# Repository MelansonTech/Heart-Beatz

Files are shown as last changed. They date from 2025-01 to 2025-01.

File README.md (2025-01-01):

Project Title: Heart Beats - Bass Note Detector
Overview:
Conceived and developed "Heart Beats," a solo endeavor aimed at creating a cost-effective, portable bass note detector with digital filters for precise bass detection and PID-controlled AGC to maintain consistent performance across a wide dynamic range. The system features an LED indicator for real-time feedback upon detecting a bass note, all powered by a single AAA battery. The pendant-style enclosure, crafted using Fusion 360, adds both functionality and aesthetics to the product.
Project Objectives:
1.	Objective 1: Design a low-cost bass note detector capable of handling a wide dynamic range.
2.	Objective 2: Implement digital filters for accurate bass note detection in music.
3.	Objective 3: Utilize PID controlled AGC to maintain consistent performance across varying input levels.
4.	Objective 4: Design a portable product with a compact form factor.
5.	Objective 5: Create an aesthetically pleasing pendant-style enclosure using Fusion 360.
Role and Responsibilities:
As the sole developer:
•	Conducted market research to identify the need for a portable and affordable bass note detector.
•	Developed digital filter algorithms for accurate bass note detection.
•	Engineered the hardware components, incorporating PID controlled AGC for dynamic range adjustment.
•	Designed and prototyped the low-power circuit ensuring compatibility with a single AAA battery.
•	Utilized Fusion 360 to design a pendant-style enclosure for user-friendly and stylish portability.
Design Process:
1.	Conceptualization: Identified the need for a portable bass note detector and outlined the key features required.
2.	Algorithm Development: Developed digital filters for precise bass note detection over a wide dynamic range.
3.	Hardware Implementation: Designed the hardware components, incorporating PID controlled AGC for dynamic range adjustment.
4.	Power Efficiency: Engineered a low-power circuit to ensure portability with a single AAA battery.
5.	Enclosure Design: Utilized Fusion 360 to design a pendant-style enclosure, considering both aesthetics and practicality.
Key Features:
1.	Digital Filters: Implemented digital filters for precise bass note detection over a wide dynamic range.
2.	PID Controlled AGC: Utilized PID control for Automatic Gain Control, ensuring consistent performance.
3.	Portability: Powered by a single AAA battery for on-the-go use without compromising performance.
4.	Compact Form Factor: Designed for easy portability and convenient use.
5.	LED Indicator: Illuminates an LED upon detecting a bass note, providing real-time feedback to the user.
6.	Pendant-style Enclosure: Designed a stylish and user-friendly pendant enclosure using Fusion 360.
Tools and Technologies:
1.	Algorithm Development: MATLAB for digital filter development.
2.	Hardware Design: Altium Designer for schematic and layout.
3.	Enclosure Design: Fusion 360 for 3D modeling and design.
Results and Achievements:
The "Heart Beats" project stands as a testament to individual innovation, successfully delivering a cost-effective, portable, and stylish bass note detector with precise digital filtering and PID-controlled AGC. The incorporation of a single AAA battery ensures portability, making it an ideal companion for music enthusiasts on the go.
Lessons Learned:
The project provided valuable insights into optimizing power consumption while maintaining performance. The Fusion 360 enclosure design emphasized the importance of both functionality and aesthetics in user-oriented products.
Conclusion:
The "Heart Beats" project exemplifies the capabilities of an individual developer in integrating digital signal processing, control systems, and industrial design to create a unique and portable bass note detector. The combination of accurate bass detection, PID-controlled AGC, and a stylish pendant-style enclosure makes "Heart Beats" a standout product in the market.
Additional Resources:
•	Link to Schematic Diagram
•	Link to Fusion 360 Enclosure Model

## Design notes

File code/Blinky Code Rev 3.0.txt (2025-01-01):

/*
 * ======== Standard MSP430 includes ========
 */
#include <msp430.h>

/*
 * ======== Grace related includes ========
 */
#include <ti/mcu/msp430/Grace.h>

int findaverage(int outavg[150], unsigned int H);
/*
 *  ======== main ========
 */
int main(void)
{
    Grace_init();   // Activate Grace-generated configuration

    	unsigned int k;   //declare unsigned integers
    	unsigned int B =0;//

    	int filtered=0; // Declare integers
  		int peak10 = 0;
  		int Adata=0;
  		int CenterTap=0;

  		int outarr[150]; // Declare Arrays

  		int RegX1[4],RegX2[4],RegY1[4],RegY2[4];

  		const float a1[]={-1.169925255,-1.402167657,-1.120723799,-1.649948614};
  		const float a2[]={0.6360640657,0.6962444294,0.8186383078,0.8846651141}; //Set the Digital filter coefficients
  		const float b0[]={-0.173675154,-0.1901072,-0.1910775392,-0.2064887892};
  		const float b2[]={0.173675154,0.1901072,0.1910775392,0.2064887892};

  		for (k=0; k>3; ++k)

  			{
  			RegX1[k]=0;
  			RegX2[k]=0;				//Clear the Digital filter multiply\accumulate registers
  			RegY1[k]=0;
  			RegY2[k]=0;
  			}

  				//-------------------------------------------------------------------------------------------------------------------------------------------------------------------------------------------------------------------------------------

  	while(1) // endless loop

  	{

  		if (P2OUT && BIT4 == BIT4) // check to see if P2OUT is equal to 00001000 and excute code if true.
  								   // Wait for timer to finish, then begin processing next data point.
  								   // A Timer is Set at 1000hz intervals and is used to set the sample rate of the ADC. P2OUT bit 4 is set by the timer.

  		{

  			ADC10CTL0 |= ENC + ADC10SC; //Start ADC

  						 /* Loop until ADC10IFG is set indicating ADC conversion complete */
  						 while ((ADC10CTL0 & ADC10IFG) == 0);
  						 Adata = ADC10MEM;

  						 for(k=0; k<3; k++) /* 3 + 0 is the number of sections - stop when 4 is reached*/

  						 {

  						 CenterTap = ((Adata * b0[k]) + (b2[k] * RegX2[k]));
  						 filtered = (CenterTap - (a1[k] * RegY1[k]) - (a2[k] * RegY2[k]));

  						 	   RegX2[k] = RegX1[k];
  						 	   RegX1[k] = Adata;
  						 	   RegY2[k] = RegY1[k];
  						 	   RegY1[k] = filtered;
  						 	   	  Adata = filtered;
  						 }

  			outarr[B]=filtered; //get 150 samples of filter
  			++B; //Set next point in array
  			P2OUT &= ~BIT4; //turn off bit 4 - timer will reset to high state and then the next sample can be processed.

  		}

			if (B > 149) //Check to see if a 150 samples have been gathered

			{

				TA0CTL &= ~BIT4; //Stop sampling and processing audio data through digital filter.
			  	peak10 = findaverage(outarr,149)*2; //find the average of the peaks of the data and multiple by 2
				B=0; // Set B to zero to begin gathering a new set of data points

			}

			if (filtered > peak10) //Check to see if the if there is a filtered data point is higher then the average of the peaks of the last 150 samples of filtered data

				 {

 					P1OUT |= BIT0;  // Turn on LED
					TA1CTL |= BIT4; //Start Timer

				}
s
  	}

}

	int findaverage(int outavg[], unsigned int H)

		{

		unsigned int X=0; //declare unsigned integers
		unsigned int D = 0;
		unsigned int M = 0;

		int peak= 0;
		int peakavg = 0;//declare integers

			for (X= 0; X < H; ) //run loop for number of samples points-->149

		  	{

				peak = 0; //set peak to zero

//-------------------------------------------------------------------------------------------------------------------------------
	//Find highest point out of every 6 data points for the total number of samples and average them.

				for (M=0;M<6;++M)

		  	    	 {

						if (outavg[X] > 0)
						{
		  	    		  if (outavg[X]> peak)
		  	    		  {
		  	    		    peak = outavg[X];
		  	    		  }
		  	    		}

						++X;
		  	    	 }

			 	 	 peakavg += peak;

			 	 	 ++D;

		  	 }

	peakavg /= D;

//-----------------------------------------------------------------------------------------------------------------------

		  	  if (peakavg < 15) //Min Peak average is 15

		  	  {
		  	  	peakavg = 15;
		  	  }

		  	TA0CTL |= BIT4; // Turn timer A0 back on and begin ADC and digial filter processing.
		  	return (peakavg);
}

/*
 *  This file is automatically generated and does not require a license
 *
 *  ==== WARNING: CHANGES TO THIS GENERATED FILE WILL BE OVERWRITTEN ====
 *
 *  To make changes to the generated code, use the space between existing
 *      "USER CODE START (section: <name>)"
 *  and
 *      "USER CODE END (section: <name>)"
 *  comments, where <name> is a single word identifying the section.
 *  Only these sections will be preserved.
 *
 *  Do not move these sections within this file or change the START and
 *  END comments in any way.
 *  ==== ALL OTHER CHANGES WILL BE OVERWRITTEN WHEN IT IS REGENERATED ====
 *
 *  This file was generated from
 *      C:/ti/grace_3_10_00_82/packages/ti/mcu/msp430/csl/interrupt_vectors/InterruptVectors_init.xdt
 */
#include <msp430.h>
#include "_Grace.h"

/* USER CODE START (section: InterruptVectors_init_c_prologue) */

/* USER CODE END (section: InterruptVectors_init_c_prologue) */

/*
 *  ======== InterruptVectors_graceInit ========
 */
void InterruptVectors_graceInit(void)
{
}

/* Interrupt Function Prototypes */

/*
 *  ======== Timer0_A3 Interrupt Service Routine ======== 
 */
#pragma vector=TIMER0_A0_VECTOR
__interrupt void TIMER0_A0_ISR_HOOK(void)
{
    /* USER CODE START (section: TIMER0_A0_ISR_HOOK) */
  P2OUT |=BIT4;

    /* USER CODE END (section: TIMER0_A0_ISR_HOOK) */
}

/*
 *  ======== Timer0_A3 Interrupt Service Routine ======== 
 */
#pragma vector=TIMER0_A1_VECTOR
__interrupt void TIMER0_A1_ISR_HOOK(void)
{
    /* USER CODE START (section: TIMER0_A1_ISR_HOOK) */
    /* replace this comment with your code */
    /* USER CODE END (section: TIMER0_A1_ISR_HOOK) */
}

/*
 *  ======== Timer1_A3 Interrupt Service Routine ======== 
 */
#pragma vector=TIMER1_A0_VECTOR
__interrupt void TIMER1_A0_ISR_HOOK(void)
{
    /* USER CODE START (section: TIMER1_A0_ISR_HOOK) */

	P1OUT &= ~BIT0; // turn off the LED
	TA1CTL &=~BIT4;// turn off timer A1

	/* USER CODE END (section: TIMER1_A0_ISR_HOOK) */
}

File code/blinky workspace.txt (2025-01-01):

/*
 * ======== Standard MSP430 includes ========
 */
#include <msp430.h>

/*
 * ======== Grace related includes ========
 */
#include <ti/mcu/msp430/Grace.h>

int findaverage(int outavg[150], unsigned int H);
/*
 *  ======== main ========
 */
int main(void)
{
    Grace_init();   // Activate Grace-generated configuration

    	unsigned int k;   //declare unsigned integers
   // 	unsigned int B =0;//
    	//int PS_offCnt=0;
    //	unsigned int underPeakTest = 0;
	//	unsigned int underPeakCounter = 0;
	//	unsigned int underPeakDetect = 0;
	//	unsigned int underPeakTestdiv = 0;
		//unsigned int peakDetectDelay = 0;
    //	unsigned int adcsample = 149;
    	int filtered=0; // Declare integers
  		unsigned int peak10 = 0;
  	//	unsigned int samplesum;
  		int Adata=0;
  		int CenterTap=0;
  		int Adata1=0;
  		int CenterTap1=0;
  		int filtered1=0;

  	//	int outarr[150]; // Declare Arrays

  		int RegX1[4],RegX2[4],RegY1[4],RegY2[4];

  		const float a1[]={-1.169925255,-1.402167657,-1.120723799,-1.649948614};
  		const float a2[]={0.6360640657,0.6962444294,0.8186383078,0.8846651141}; //Set the Digital filter coefficients
  		const float b0[]={-0.173675154,-0.1901072,-0.1910775392,-0.2064887892};
  		const float b2[]={0.173675154,0.1901072,0.1910775392,0.2064887892};

  		int RegX11 =0;
  		int RegY11 = 0;

  		const float a11 =  -0.678222413648525757;
  		//const float a21 = 0; //Set the Digital filter coefficients
  		const float b01 = 0.160888793175737121;
  		const float b11 = 0.160888793175737121;

  		for (k=0; k>3; ++k)

  			{
  			RegX1[k]=0;
  			RegX2[k]=0;				//Clear the Digital filter multiply\accumulate registers
  			RegY1[k]=0;
  			RegY2[k]=0;
  			}

  	//P1OUT &= 0;
  	//P1OUT |=BIT0; // turn on the LED/also used to as a flag to debounce the on off switch
  //	TA1CTL &=~BIT4;

  				//-------------------------------------------------------------------------------------------------------------------------------------------------------------------------------------------------------------------------------------

  	//while(P1OUT && BIT0 == BIT0)

 // 	{

  //	TA1CTL |= BIT4; //Start Timer//wait for the on\off button to be released

  //	if (!(P2IN & BIT1))

  //	{

  	//	TA1CCR0 += 600;

  //	}

  //	}

 // 	P2OUT |= BIT2;//latch the power supply on
  //	TA1CCR0 = 600;

  	while(1) // endless loop

  	{

  		P1OUT &= ~BIT1;

  		if (P2OUT && BIT4 == BIT4) // check to see if P2OUT is equal to 00001000 and excute code if true.
  								   // Wait for timer to finish, then begin processing next data point.
  								   // A Timer is Set at 1000hz intervals and is used to set the sample rate of the ADC. P2OUT bit 4 is set by the timer.

  		{

  			P2OUT &= ~BIT4; //turn off bit 4 - timer will reset to high state and then the next sample can be processed.
  			P1OUT |= BIT1;
  			ADC10CTL0 |= ENC + ADC10SC; //Start ADC

  						 /* Loop until ADC10IFG is set indicating ADC conversion complete */
  						 while ((ADC10CTL0 & ADC10IFG) == 0);
  						 Adata = ADC10MEM;

  						 for(k=0; k<3; k++) /* 3 + 0 is the number of sections - stop when 4 is reached*/

  						 {

  						 CenterTap = ((Adata * b0[k]) + (b2[k] * RegX2[k]));
  						 filtered = (CenterTap - (a1[k] * RegY1[k]) - (a2[k] * RegY2[k]));

  						 	   RegX2[k] = RegX1[k];
  						 	   RegX1[k] = Adata;
  						 	   RegY2[k] = RegY1[k];
  						 	   RegY1[k] = filtered;
  						 	   Adata = filtered;
  						 }

  		if (filtered < 0)

  			{

  			filtered *= -1;

  			}

  		 CenterTap1 = ((filtered * b01) + (b11 * RegX11));
  		 filtered1 = (CenterTap1 - (a11 * RegY11));

  		  		 //RegX2[k] = RegX1[k];
  		  		 RegX11 = filtered;
  		  		// RegY2[k] = RegY1[k];
  		  		 RegY11 = filtered1;
  		  		 peak10 = filtered1;

  			if (peak10 < 5)

  			{
				 peak10 = 5;

  			}

  			peak10 *= 3;

		//	if (B > adcsample) //Check to see if a 150 samples have been gathered

		//	{

				//TA0CTL &= ~BIT4; //Stop sampling and processing audio data through digital filter.
			  	//peak10 = findaverage(outarr, B); //find the average of the peaks of the data and multiple by 2
			//	B=0; // Set B to zero to begin gathering a new set of data points

		//	}
				/*
				if (!(P2IN & BIT1))

				{

		 	PS_offCnt += 1;

		}

				else

				{

				PS_offCnt = 0;

				}

				if (PS_offCnt > 3 )

				{

					while(1)

				{
					P2OUT &= ~BIT2;

				}

				}

			}

 */
			//filtered *= adcsample;

			if (filtered > peak10) //Check to see if the if there is a filtered data point is higher then the average of the peaks of the last 150 samples of filtered data

				 {

				P1OUT |= (BIT0 + BIT2);  // Turn on LED
				TA1CTL |= BIT4; //Start Timer

				//P2OUT &= ~BIT4; //turn off bit 4 - timer will reset to high state and then the next sample can be processed.

  /*
				if (underPeakTest < filtered)

				{
				underPeakTest = filtered;
				underPeakTestdiv = underPeakTest/2;
				underPeakCounter = 10;
				underPeakDetect = 1;

				}

				 }

			if (underPeakDetect == 1)

			{
			//	peakDetectDelay++;

		//	if (peakDetectDelay == 8)

		//		{

				if ( filtered < underPeakTestdiv)

				{

				underPeakCounter++;

				}

				else

				{

		//			peakDetectDelay = 0;
					underPeakCounter--;

				}

			if (underPeakCounter > 100)

				{

				P1OUT |= (BIT0 + BIT2);  // Turn on LED
				TA1CTL |= BIT4; //Start Timer
				underPeakDetect = 0;
				//peakDetectDelay = 0;
				underPeakTest = 0;

				}

			if (underPeakCounter < 8)

			{

			underPeakDetect = 0;
			underPeakTest = 0;

			}

   */

  	}

}

}

}
/*

	int findaverage(int outavg[], unsigned int H)

		{

		unsigned int X=0; //declare unsigned integers
		unsigned int D = 0;
		unsigned int M = 0;

		int peak= 0;
		int peakavg = 0;//declare integers

			for (X= 0; X < H; ) //run loop for number of samples points-->149

		  	{

				peak = 0; //set peak to zero

//-------------------------------------------------------------------------------------------------------------------------------
	//Find highest point out of every 6 data points for the total number of samples and average them.

				for (M=0;M<6;++M)

		  	    	 {

						if (outavg[X] > 0)
						{
		  	    		  if (outavg[X]> peak)
		  	    		  {
		  	    		    peak = outavg[X];
		  	    		  }
		  	    		}

						++X;
		  	    	 }

			 	 	 peakavg += peak;

			 	 	 ++D;

		  	 }

	peakavg /= D;

//-----------------------------------------------------------------------------------------------------------------------

		  	  if (peakavg < 5) //Min Peak average is 15

		  	  {
		  	  	peakavg = 5;
		  	  }

		  	  peakavg *= 2.5;

		  	TA0CTL |= BIT4; // Turn timer A0 back on and begin ADC and digial filter processing.
		  	return (peakavg);

}
*/

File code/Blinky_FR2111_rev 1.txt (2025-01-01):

#include <msp430.h>

//void Software_Trim();                       // Software Trim to get the best DCOFTRIM value
//#define MCLK_FREQ_MHZ 8                     // MCLK = 8MHz

unsigned int ADCCOMPLETE_FLAG = 0;
int Adata;
int main(void)
{

    WDTCTL = WDTPW | WDTHOLD;                 // Stop WDT

        // Configure one FRAM waitstate as required by the device datasheet for MCLK
        // operation beyond 8MHz _before_ configuring the clock system.
        FRCTL0 = FRCTLPW | NWAITS_1;

        __bis_SR_register(SCG0);                     // disable FLL
        CSCTL3 |= SELREF__XT1CLK;                    // Set XT1 as FLL reference source
        CSCTL0 = 0;                                  // clear DCO and MOD registers
        CSCTL1 &= ~(DCORSEL_7);                      // Clear DCO frequency select bits first
        CSCTL1 |= DCORSEL_5;                         // Set DCO = 16MHz
        CSCTL2 = FLLD_0 + 487;                       // DCOCLKDIV = 16MHz
        __delay_cycles(3);
        __bic_SR_register(SCG0);                     // enable FLL
        while(CSCTL7 & (FLLUNLOCK0 | FLLUNLOCK1));   // FLL locked

  /*
        __bis_SR_register(SCG0);                // disable FLL
       CSCTL3 |= SELREF__REFOCLK;              // Set REFO as FLL reference source
       CSCTL1 = DCOFTRIMEN_1 | DCOFTRIM0 | DCOFTRIM1 | DCORSEL_3;// DCOFTRIM=3, DCO Range = 8MHz
       CSCTL2 = FLLD_0 + 243;                  // DCODIV = 8MHz
       __delay_cycles(3);
       __bic_SR_register(SCG0);                // enable FLL
       Software_Trim();                        // Software Trim to get the best DCOFTRIM value

       CSCTL4 = SELMS__DCOCLKDIV | SELA__REFOCLK; // set default REFO(~32768Hz) as ACLK source, ACLK = 32768Hz
                                               // default DCODIV as MCLK and SMCLK source
*/

    // GPIO config

       P1DIR |= BIT1;
       P2DIR |= BIT0 + BIT1;                    // P2.0 and P2.1 output
       P2SEL0 |= BIT0 + BIT1;                   // P2.0 and P2.1 options select
       P1SEL0 |= BIT5;                          // Configure ADC A1 pin
       P1SEL1 |= BIT5;

       // timer config
      const unsigned int TimerPeriod = 26666;
      const unsigned int AGC_duty = 14500;
      const unsigned int AmpRef_duty = 6060;

          // Disable the GPIO power-on default high-impedance mode to activate
          // previously configured port settings
          PM5CTL0 &= ~LOCKLPM5;
          SYSCFG3 |= TBRMP;                         //0b = P1.x is selected P1.6 and P1.7  1b = P2.0 and P2.1
          TB0CCR0 = TimerPeriod-1;                  // PWM Period
          TB0CCTL1 = OUTMOD_7;                      // CCR1 reset/set
          TB0CCR1 = AmpRef_duty;                       // CCR1 PWM duty cycle
          TB0CCTL2 = OUTMOD_7;                      // CCR2 reset/set
          TB0CCR2 = AGC_duty;                       // CCR2 PWM duty cycle
          TB0CTL = TBSSEL__SMCLK | MC__UP | TBCLR;  // SMCLK, up mode, clear TBR
          TB0CCTL0 |= CCIE;

          // Disable the GPIO power-on default high-impedance mode to activate
             // previously configured port settings
             PM5CTL0 &= ~LOCKLPM5;

             // Configure ADC10
             ADCCTL0 |= ADCSHT_2 | ADCON;                              // ADCON, S&H=16 ADC clks
             ADCCTL1 |= ADCSHP;                                        // ADCCLK = MODOSC; sampling timer
             ADCCTL2 |= ADCRES;                                        // 10-bit conversion results
             ADCIE |= ADCIE0;                                          // Enable ADC conv complete interrupt
             ADCMCTL0 |= ADCINCH_5 | ADCSREF_1;                        // A1 ADC input select; Vref=1.5V

             // Configure reference
             PMMCTL0_H = PMMPW_H;                                      // Unlock the PMM registers
             PMMCTL2 |= INTREFEN;                                      // Enable internal reference
             __delay_cycles(400);                                      // Delay for reference settling

        unsigned int k=0;                           //declare unsigned integers
        unsigned int LEDTIMER=0;
        int peakAvg = 0;
        int BassBoundryNow = 0;
        int Peak_search_Arr_i =0;
        int Peak_search_Arr[64];
        int sampleCount=0;                            // Declare integers
        int SampleCountLimit = 255;
        int Peak_search_window = 0;
        int BassBoundry = 0;
        int filtered = 0;
        int CenterTap=0;
        int flipFlop = 0;

       // int Peak_search_Arr[25]; // Declare Arrays

        //PID Variables

         int INT_LIMIT = 5;
         int setpoint = 700;                        //PID controller input
         int peakHold_Now;
         int peakHold_Last;
         float error;
         float errSum;
         float dErr;
         float PID_out;
         float kp = 0.02;
         float ki = 0.0001;
         float kd = 0.01;
         int peakHold_decay = 1;
         P1OUT |= BIT1;

     ////    for (k=0; k < 25; ++k)

        //     {
         //    Peak_search_Arr[k]=0;   //clear the avg filter array
       //      }

                  int RegX1[4],RegX2[4],RegY1[4],RegY2[4];

                  const float a1[]={-1.169925255,-1.402167657,-1.120723799,-1.649948614};
                  const float a2[]={0.6360640657,0.6962444294,0.8186383078,0.8846651141}; //Set the Digital filter coefficients
                  const float b0[]={-0.173675154,-0.1901072,-0.1910775392,-0.2064887892};
                  const float b2[]={0.173675154,0.1901072,0.1910775392,0.2064887892};

                  for (k=0; k<3; ++k)

                      {
                      RegX1[k]=0;
                      RegX2[k]=0;             //Clear the Digital filter multiply\accumulate registers
                      RegY1[k]=0;
                      RegY2[k]=0;
                      }

                          //-------------------------------------------------------------------------------------------------------------------------------------------------------------------------------------------------------------------------------------

              //__delay_cycles(1600000);

              while(1) // endless loop

              {
                  __bis_SR_register(LPM0_bits | GIE);

                  if (ADCCOMPLETE_FLAG == 1) // check to see if P2OUT is equal to 00001000 and excute code if true.
                                             // Wait for timer to finish, then begin processing next data point.
                                             // A Timer is Set at 1000hz intervals and is used to set the sample rate of the ADC. P2OUT bit 4 is set by the timer.

                  {

                     // P1OUT ^=BIT1;
                      ADCCOMPLETE_FLAG = 0;
                      ADCCTL0 |= ADCENC | ADCSC;             // Sampling and conversion start
                      __bis_SR_register(LPM0_bits | GIE);

                     if  (Adata > peakHold_Now) {                  // get and hold the peak to be used for PID controller

                      peakHold_Now += Adata/10;

                     }

                      peakHold_Now -=peakHold_decay;                         //slowly discharge the peak

                      error =  setpoint - peakHold_Now;
                      errSum += error;

                      if (errSum > 100)
                      {
                          errSum = INT_LIMIT;
                      }

                      if (errSum < -INT_LIMIT){

                          errSum = -INT_LIMIT;
                      }

                      dErr = peakHold_Now - peakHold_Last;

                      PID_out = (kp * error) + (ki *errSum) + (kd* dErr);

                      peakHold_Last = peakHold_Now;

                      TB0CCR2 += PID_out;

                      if (TB0CCR2 > 14000){

                          TB0CCR2 = 14000;
                      }

                      if (TB0CCR2 < 10500){

                          TB0CCR2 = 10500;
                      }

                      if ( P1OUT && BIT1 == BIT1 )

                          {
                              if (LEDTIMER < 200)
                              {
                                  LEDTIMER++;
                              }
                              else
                              {
                                  LEDTIMER = 0;
                                  P1OUT &=~BIT1;
                              }

                          }

                             for(k=0; k<3; k++) /* 3 + 0 is the number of sections - stop when 4 is reached*/

                                   {

                                   CenterTap = ((Adata * b0[k]) + (b2[k] * RegX2[k]));
                                   filtered = (CenterTap - (a1[k] * RegY1[k]) - (a2[k] * RegY2[k]));

                                         RegX2[k] = RegX1[k];
                                         RegX1[k] = Adata;
                                         RegY2[k] = RegY1[k];
                                         RegY1[k] = filtered;
                                         Adata = filtered;
                                   }

                             if (filtered < 0)
                             {
                                 filtered *=-1;
                             }

                             if (filtered > peakAvg)

                             {

                             peakAvg = filtered;

                             }

                             ++Peak_search_window;

                             if (Peak_search_window > 6 && sampleCount < 64){

                                 Peak_search_window= 0;
                                 peakAvg /= 64;
                                 BassBoundryNow -= Peak_search_Arr[Peak_search_Arr_i];
                                 BassBoundryNow += peakAvg;
                                 Peak_search_Arr[Peak_search_Arr_i] =  peakAvg;
                                 peakAvg = 0;
                                 ++ Peak_search_Arr_i;
                                 ++sampleCount;

                             }

                             if (sampleCount > 64){

                                 ++flipFlop;

                                 if (flipFlop > 1){

                                 flipFlop = 0;
                                 --BassBoundry;

                                 }
                             }

                                 if (sampleCount > 64 && BIT1 == P1OUT & BIT1)
                                {

                                    sampleCount = 0;
                                    Peak_search_Arr_i = 0;
                                    BassBoundry = BassBoundryNow;

                                }

                                if (BassBoundry > 1024){

                                    BassBoundry = 1024;
                                }

                                if (BassBoundry < 1){

                                   BassBoundry = 1;

                                }

                                if (filtered > BassBoundry*2 && filtered > 60)
                                     {
                                          P1OUT |= BIT1;
                                     }

                              //    P1OUT ^=BIT1;
                  }

              }
          }

// ADC interrupt service routine
#if defined(__TI_COMPILER_VERSION__) || defined(__IAR_SYSTEMS_ICC__)
#pragma vector=ADC_VECTOR
__interrupt void ADC_ISR(void)
#elif defined(__GNUC__)
void __attribute__ ((interrupt(ADC_VECTOR))) ADC_ISR (void)
#else
#error Compiler not supported!
#endif

{
    switch(__even_in_range(ADCIV,ADCIV_ADCIFG))
    {

        case ADCIV_ADCIFG:
            Adata = ADCMEM0;
            __bic_SR_register_on_exit(LPM0_bits);            // Clear CPUOFF bit from LPM0
            break;
        default:
            break;
    }
}

              // Timer B0 interrupt service routine
              #if defined(__TI_COMPILER_VERSION__) || defined(__IAR_SYSTEMS_ICC__)
              #pragma vector = TIMER0_B0_VECTOR
              __interrupt void Timer_B (void)
              #elif defined(__GNUC__)
              void __attribute__ ((interrupt(TIMER0_B0_VECTOR))) Timer_B (void)
              #else
              #error Compiler not supported!
              #endif
{
         ADCCOMPLETE_FLAG = 1;
         __bic_SR_register_on_exit(LPM0_bits);              // Clear CPUOFF bit from LPM0
}

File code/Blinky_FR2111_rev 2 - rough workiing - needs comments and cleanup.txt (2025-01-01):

#include <msp430.h>

//void Software_Trim();                       // Software Trim to get the best DCOFTRIM value
//#define MCLK_FREQ_MHZ 8                     // MCLK = 8MHz

unsigned int ADCCOMPLETE_FLAG = 0;
int Adata;
int main(void)
{

    WDTCTL = WDTPW | WDTHOLD;                 // Stop WDT

        // Configure one FRAM waitstate as required by the device datasheet for MCLK
        // operation beyond 8MHz _before_ configuring the clock system.
        FRCTL0 = FRCTLPW | NWAITS_1;

        __bis_SR_register(SCG0);                     // disable FLL
        CSCTL3 |= SELREF__XT1CLK;                    // Set XT1 as FLL reference source
        CSCTL0 = 0;                                  // clear DCO and MOD registers
        CSCTL1 &= ~(DCORSEL_7);                      // Clear DCO frequency select bits first
        CSCTL1 |= DCORSEL_5;                         // Set DCO = 16MHz
        CSCTL2 = FLLD_0 + 487;                       // DCOCLKDIV = 16MHz
        __delay_cycles(3);
        __bic_SR_register(SCG0);                     // enable FLL
        while(CSCTL7 & (FLLUNLOCK0 | FLLUNLOCK1));   // FLL locked

  /*
        __bis_SR_register(SCG0);                // disable FLL
       CSCTL3 |= SELREF__REFOCLK;              // Set REFO as FLL reference source
       CSCTL1 = DCOFTRIMEN_1 | DCOFTRIM0 | DCOFTRIM1 | DCORSEL_3;// DCOFTRIM=3, DCO Range = 8MHz
       CSCTL2 = FLLD_0 + 243;                  // DCODIV = 8MHz
       __delay_cycles(3);
       __bic_SR_register(SCG0);                // enable FLL
       Software_Trim();                        // Software Trim to get the best DCOFTRIM value

       CSCTL4 = SELMS__DCOCLKDIV | SELA__REFOCLK; // set default REFO(~32768Hz) as ACLK source, ACLK = 32768Hz
                                               // default DCODIV as MCLK and SMCLK source
*/

    // GPIO config

       P1DIR |= BIT1;
       P2DIR |= BIT0 + BIT1;                    // P2.0 and P2.1 output
       P2SEL0 |= BIT0 + BIT1;                   // P2.0 and P2.1 options select
       P1SEL0 |= BIT5;                          // Configure ADC A1 pin
       P1SEL1 |= BIT5;

       // timer config
      const unsigned int TimerPeriod = 26666;
      const unsigned int AGC_duty = 14500;
      const unsigned int AmpRef_duty = 6060;

          // Disable the GPIO power-on default high-impedance mode to activate
          // previously configured port settings
          PM5CTL0 &= ~LOCKLPM5;
          SYSCFG3 |= TBRMP;                         //0b = P1.x is selected P1.6 and P1.7  1b = P2.0 and P2.1
          TB0CCR0 = TimerPeriod-1;                  // PWM Period
          TB0CCTL1 = OUTMOD_7;                      // CCR1 reset/set
          TB0CCR1 = AmpRef_duty;                       // CCR1 PWM duty cycle
          TB0CCTL2 = OUTMOD_7;                      // CCR2 reset/set
          TB0CCR2 = AGC_duty;                       // CCR2 PWM duty cycle
          TB0CTL = TBSSEL__SMCLK | MC__UP | TBCLR;  // SMCLK, up mode, clear TBR
          TB0CCTL0 |= CCIE;

          // Disable the GPIO power-on default high-impedance mode to activate
             // previously configured port settings
             PM5CTL0 &= ~LOCKLPM5;

             // Configure ADC10
             ADCCTL0 |= ADCSHT_2 | ADCON;                              // ADCON, S&H=16 ADC clks
             ADCCTL1 |= ADCSHP;                                        // ADCCLK = MODOSC; sampling timer
             ADCCTL2 |= ADCRES;                                        // 10-bit conversion results
             ADCIE |= ADCIE0;                                          // Enable ADC conv complete interrupt
             ADCMCTL0 |= ADCINCH_5 | ADCSREF_1;                        // A1 ADC input select; Vref=1.5V

             // Configure reference
             PMMCTL0_H = PMMPW_H;                                      // Unlock the PMM registers
             PMMCTL2 |= INTREFEN;                                      // Enable internal reference
             __delay_cycles(400);                                      // Delay for reference settling

        unsigned int k=0;                           //declare unsigned integers
        unsigned int LEDTIMER=0;
        int BassBoundryNow = 0;
        long long int BassBoundry = 0;
        int filtered = 0;
        int CenterTap=0;
        long unsigned int filteredScaled;
        int LEDon;

       // int Peak_search_Arr[25]; // Declare Arrays

        //PID Variables

         int INT_LIMIT = 5;
         int setpoint = 700;                        //PID controller input
         int peakHold_Now;
         int peakHold_Last;
         float error;
         float errSum;
         float dErr;
         float PID_out;
         float kp = 0.02;
         float ki = 0.0001;
         float kd = 0.01;
         int peakHold_decay = 1;
         P1OUT |= BIT1;

                  int RegX1[4],RegX2[4],RegY1[4],RegY2[4];

                  const float a1[]={-1.169925255,-1.402167657,-1.120723799,-1.649948614};
                  const float a2[]={0.6360640657,0.6962444294,0.8186383078,0.8846651141}; //Set the Digital filter coefficients
                  const float b0[]={-0.173675154,-0.1901072,-0.1910775392,-0.2064887892};
                  const float b2[]={0.173675154,0.1901072,0.1910775392,0.2064887892};

                  for (k=0; k<3; ++k)

                      {
                      RegX1[k]=0;
                      RegX2[k]=0;             //Clear the Digital filter multiply\accumulate registers
                      RegY1[k]=0;
                      RegY2[k]=0;
                      }

                          //-------------------------------------------------------------------------------------------------------------------------------------------------------------------------------------------------------------------------------------

              while(1) // endless loop

              {
                  __bis_SR_register(LPM0_bits | GIE);

                  if (ADCCOMPLETE_FLAG == 1) // check to see if P2OUT is equal to 00001000 and excute code if true.
                                             // Wait for timer to finish, then begin processing next data point.
                                             // A Timer is Set at 1000hz intervals and is used to set the sample rate of the ADC. P2OUT bit 4 is set by the timer.

                  {

                     // P1OUT ^=BIT1;
                      ADCCOMPLETE_FLAG = 0;
                      ADCCTL0 |= ADCENC | ADCSC;             // Sampling and conversion start
                      __bis_SR_register(LPM0_bits | GIE);

                     if  (Adata > peakHold_Now) {                  // get and hold the peak to be used for PID controller

                      peakHold_Now += Adata/10;

                     }

                      peakHold_Now -=peakHold_decay;                         //slowly discharge the peak

                      error =  setpoint - peakHold_Now;
                      errSum += error;

                      if (errSum > 100)
                      {
                          errSum = INT_LIMIT;
                      }

                      if (errSum < -INT_LIMIT){

                          errSum = -INT_LIMIT;
                      }

                      dErr = peakHold_Now - peakHold_Last;

                      PID_out = (kp * error) + (ki *errSum) + (kd* dErr);

                      peakHold_Last = peakHold_Now;

                      TB0CCR2 += PID_out;

                      if (TB0CCR2 > 14000){

                          TB0CCR2 = 14000;
                      }

                      if (TB0CCR2 < 10500){

                          TB0CCR2 = 10500;
                      }

                      if ( LEDon == 1 )

                          {
                                  if (LEDTIMER < 200)
                                  {
                                  LEDTIMER++;
                                  }
                                  else
                                  {
                                  LEDTIMER = 0;
                                  P1OUT &=~BIT1;
                                  LEDon = 0;
                                  }

                          }

                             for(k=0; k<3; k++) /* 3 + 0 is the number of sections - stop when 4 is reached*/

                                   {

                                   CenterTap = ((Adata * b0[k]) + (b2[k] * RegX2[k]));
                                   filtered = (CenterTap - (a1[k] * RegY1[k]) - (a2[k] * RegY2[k]));

                                         RegX2[k] = RegX1[k];
                                         RegX1[k] = Adata;
                                         RegY2[k] = RegY1[k];
                                         RegY1[k] = filtered;
                                         Adata = filtered;
                                   }

                             if (filtered < 0)
                             {
                                 filtered *=-1;
                             }

                             filteredScaled = filtered;
                             filteredScaled *= 100;

                             if (filteredScaled > BassBoundry)
                                   {

                                       P1OUT |= BIT1;
                                       LEDon = 1;

                                   }

                             if (LEDon == 0)

                              {

                              BassBoundry-= 5;

                              }

                                 if (BassBoundry <3000)

                                   {
                                       BassBoundry = 3000;
                                   }

                                if (filteredScaled > BassBoundry)

                                {
                                    BassBoundry = filtered;
                                    BassBoundry *= 90;

                                }

                  }
              }
          }

// ADC interrupt service routine
#if defined(__TI_COMPILER_VERSION__) || defined(__IAR_SYSTEMS_ICC__)
#pragma vector=ADC_VECTOR
__interrupt void ADC_ISR(void)
#elif defined(__GNUC__)
void __attribute__ ((interrupt(ADC_VECTOR))) ADC_ISR (void)
#else
#error Compiler not supported!
#endif

{
    switch(__even_in_range(ADCIV,ADCIV_ADCIFG))
    {

        case ADCIV_ADCIFG:
            Adata = ADCMEM0;
            __bic_SR_register_on_exit(LPM0_bits);            // Clear CPUOFF bit from LPM0
            break;
        default:
            break;
    }
}

              // Timer B0 interrupt service routine
              #if defined(__TI_COMPILER_VERSION__) || defined(__IAR_SYSTEMS_ICC__)
              #pragma vector = TIMER0_B0_VECTOR
              __interrupt void Timer_B (void)
              #elif defined(__GNUC__)
              void __attribute__ ((interrupt(TIMER0_B0_VECTOR))) Timer_B (void)
              #else
              #error Compiler not supported!
              #endif
{
         ADCCOMPLETE_FLAG = 1;
         __bic_SR_register_on_exit(LPM0_bits);              // Clear CPUOFF bit from LPM0
}

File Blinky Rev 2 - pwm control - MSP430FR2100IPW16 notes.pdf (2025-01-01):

C4 | Bias
C3 | Bias

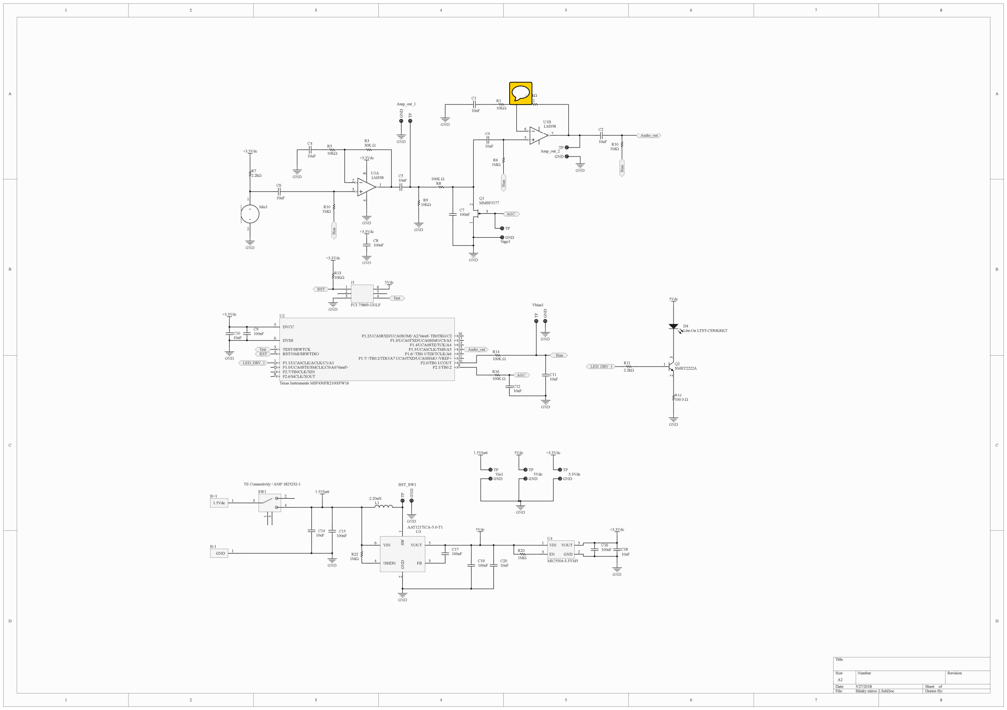
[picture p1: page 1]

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
Title

Size | Number | Revision
A2
Date: | 5/27/2018 | Sheet of
File: | Blinky mirco 2.SchDoc | Drawn By: ¹ ² | 3

Q1
MMBFJ177

2.2kΩ

R11

100.0 Ω

R12

1 2 3 Q2

SMBT2222A

100nF

C17

1 6
2 5
3 4

J1

FCI 75869-131LF

VIN 6

!SHDN 4

VOUT | 5
FB | 3 SW

## 1 GND

2

AAT1217ICA-5.0-T1
U3

VIN 1

GND | 2 EN 3
VOUT | 5

U4

MIC5504-3.3YM5

2.2kΩ

R7

10uF

C6

10uF

GND

+3.3Vdc

10uF

C5

30K Ω

R3

GND

GND | 100K Ω R8

GND

100nF

C7

10uF

475 kΩ
R2

10uF

C1

GND

+3.3Vdc

# GND⁺

1

2

Mic1

1.5Vbatt

100nF

C19

100nF

C15

10uF

C20

10uF

100nF C18

C16

10uF

C14 | 5Vdc

GND

+3.3Vdc

2.20uH
L1

100nF

C8

GND

+3.3Vdc

100nF

C9

GND

+3.3Vdc

RST

Test

GND

5Vdc

+3.3Vdc

10uF

C10

GND

LED_DRV_1

GND

GND | GND | TP

Amp_out_1

GND
TP

GND

Amp_out_2

GND TP GND

BST_SW1

GND

TP

GND

5Vdc

TP

GND

3.3Vdc

5Vdc | +3.3Vdc

GND

10KΩ

R9

10KΩ

R5

10KΩ

R13

10KΩ

R1

1MΩ

R10

1MΩ

R6

1MΩ

R20

5Vdc

TP

GND

Vin1

1.5Vbatt

1MΩ

GND | R22

1

B-1

1.5Vdc 1

B+1

2

3

### 1 ⁸ 4

U1A
LM358

AGC

3
4

2 1

5

SW1

TE Connectivity / AMP 1825232-1

P1.1/UCA0CLK/ACLK/C1/A1 1
P1.0/UCA0STE/SMCLK/C0/A0/Veref+ 2

TEST/SBWTCK 3
RST/NMI/SBWTDIO 4

DVCC 5

DVSS 6

P2.7/TB0CLK/XIN 7
P2.6/MCLK/XOUT 8
P2.1/TB0.2 | 9
P2.0/TB0.1/COUT | 10 P1.7/ /TB0.2/TDO/A7 UCA0TXD/UCA0SIMO /VREF+ | 11 P1.6/ /TB0.1/TDI/TCLK/A6 | 12 P1.5/UCA0CLK/TMS/A5 | 13 P1.4/UCA0STE/TCK/A4 | 14 P1.3/UCA0TXD/UCA0SIMO/C3/A3 | 15 P1.2/UCA0RXD/UCA0SOMI/ A2/Veref- TB0TRG/C2 | 16

U2

Texas Instruments MSP430FR2100IPW16

RST

Test

100K Ω

R14

10uF

C11

GND

Bias

AGC

10uF

C12

10uF

C2

Audio_out

Audio_out

100K Ω

R16 | TP | GND

Vbias1

TP

GND
Vagc1

GND

5

6
7

U1B
LM358

D4
Lite-On LTST-C930KRKT
LED_DRV_1 | Bias

1MΩ

R10

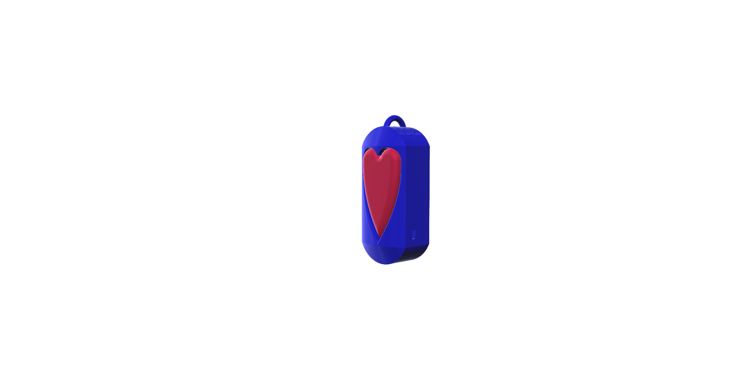
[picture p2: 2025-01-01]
chassis/123d/Rev 8 final/Heartbeat chassis SS.png

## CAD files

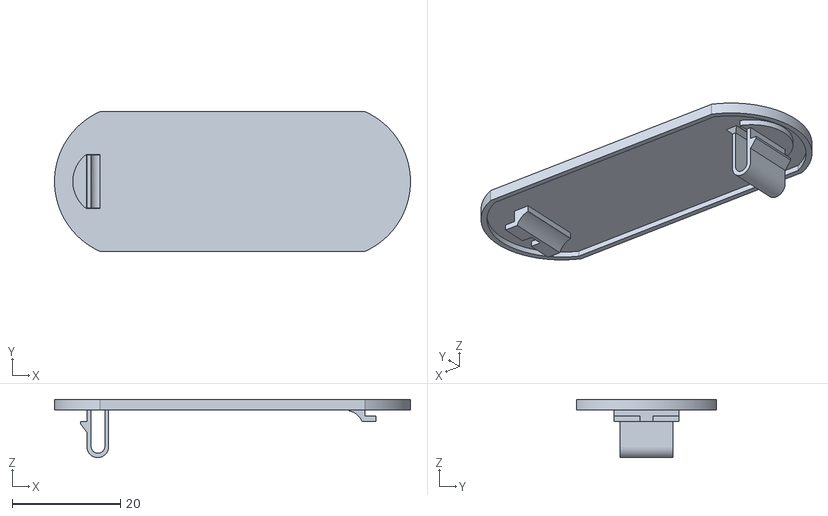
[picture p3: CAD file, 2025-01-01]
chassis/123d/Rev 5 complete/STL/Cover.stl
65.8 x 25.8 x 10.8

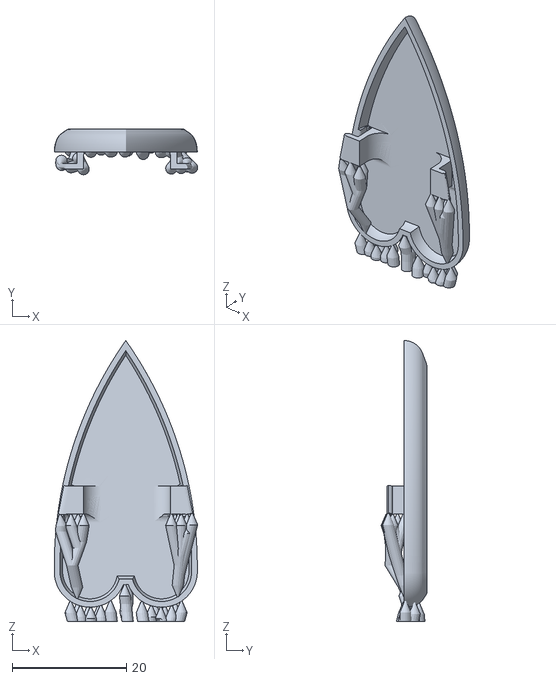
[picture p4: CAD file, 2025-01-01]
chassis/123d/Rev 7/rev 7 work space/plate rev 7-1struts.stl
25.1 x 8.00 x 49.1

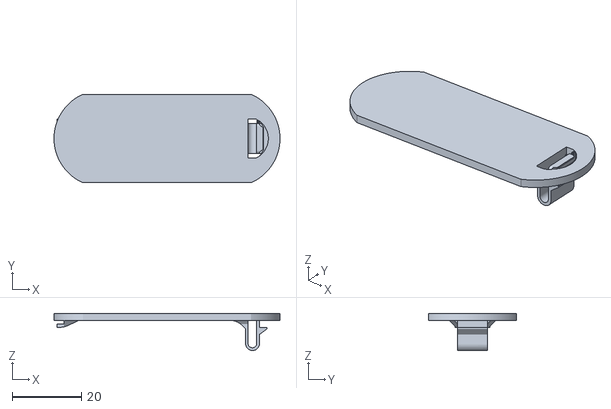
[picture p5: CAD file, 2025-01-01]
chassis/123d/Rev 8 final/STLs/cover support test 1.stl
65.4 x 25.6 x 10.8

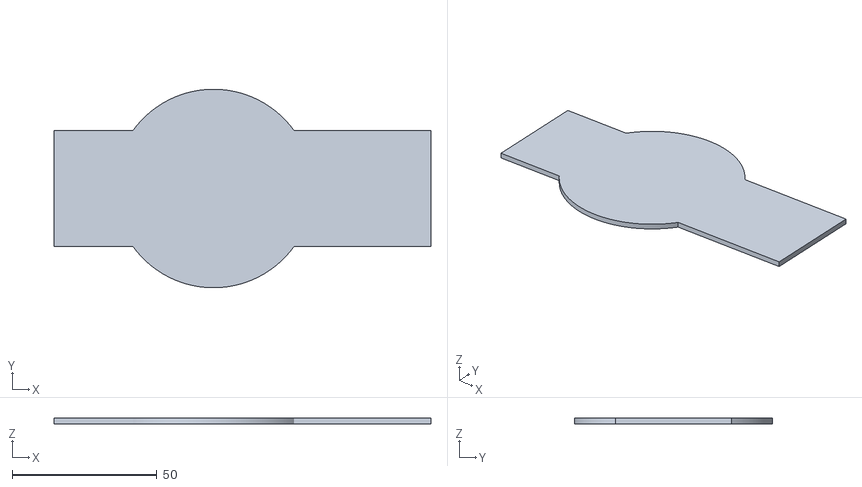
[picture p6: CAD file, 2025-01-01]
chassis/Hat medium/stencil.stl
130.0 x 68.4 x 2.00

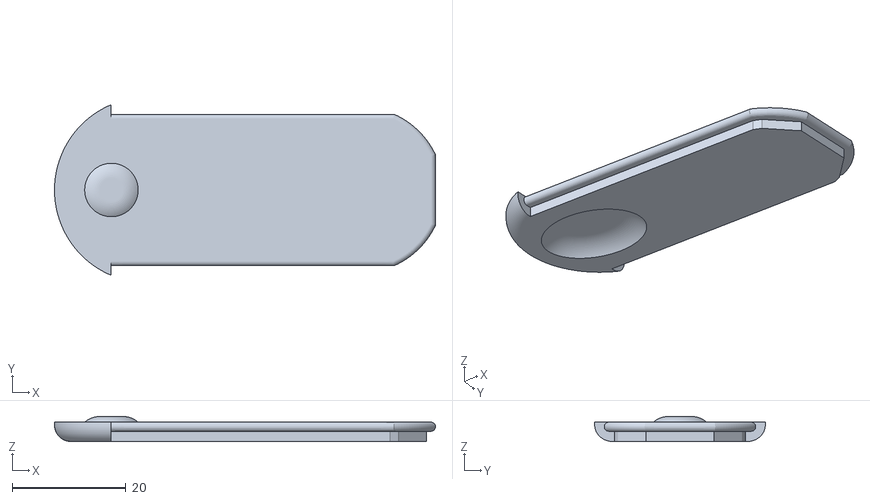
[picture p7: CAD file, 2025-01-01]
chassis/Remodel/STLs JUN17/Cover JUN17 - 4.stl
66.9 x 30.0 x 4.40

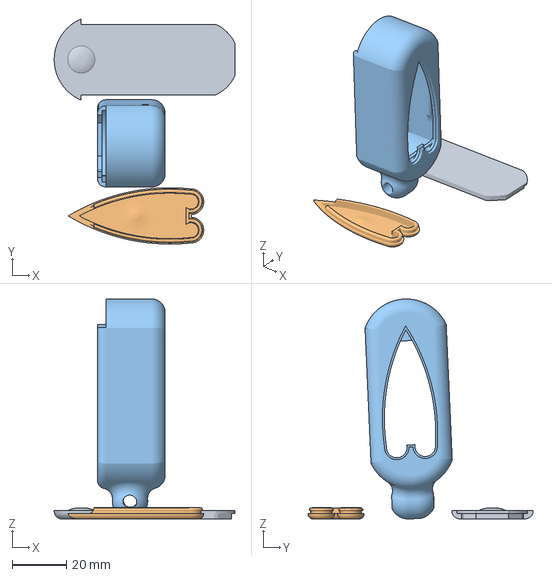
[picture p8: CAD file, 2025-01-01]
chassis/Remodel/test prints/PI3MK2_chassis 10.3mf
66.6 x 83.0 x 81.1 mm

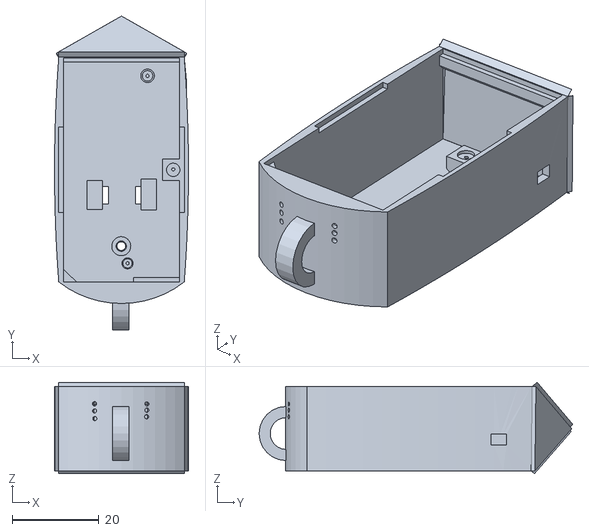
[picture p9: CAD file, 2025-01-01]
chassis/STLs/chassis 3.0.stl
31.0 x 72.5 x 21.1

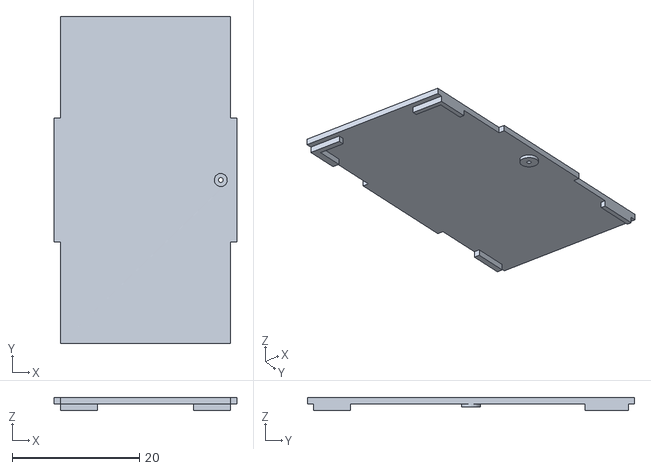
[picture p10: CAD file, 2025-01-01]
chassis/STLs/Rev 3.0/Cover Rev 3.0.stl
28.8 x 51.5 x 2.00

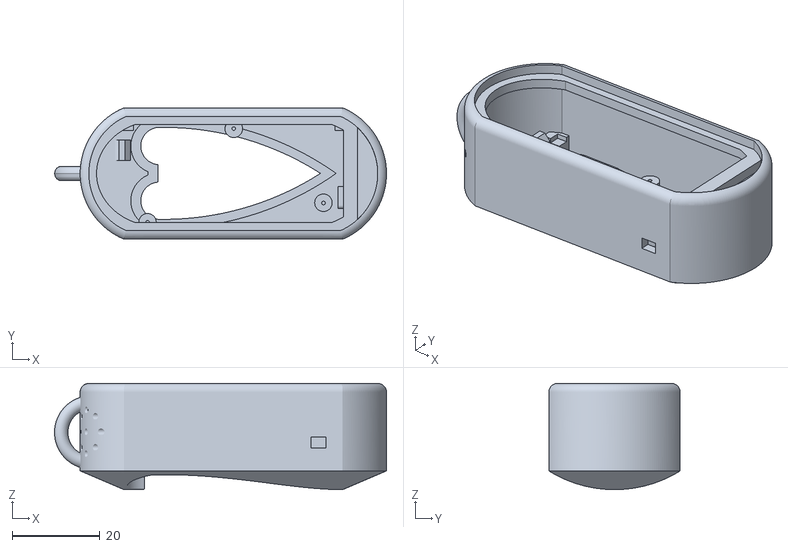
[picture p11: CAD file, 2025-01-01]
chassis/123d/Rev 5 complete/STL/Chassis.stl
75.9 x 30.0 x 24.3

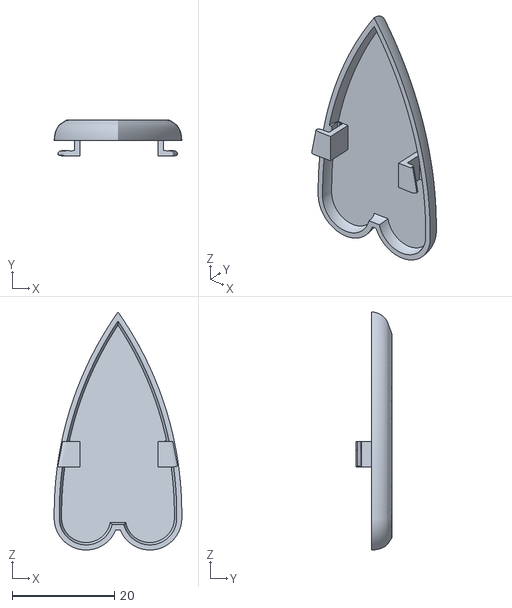
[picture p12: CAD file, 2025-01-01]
chassis/123d/Rev 7/rev 7 work space/plate rev 7 thicker 2.stl
25.0 x 7.00 x 46.6

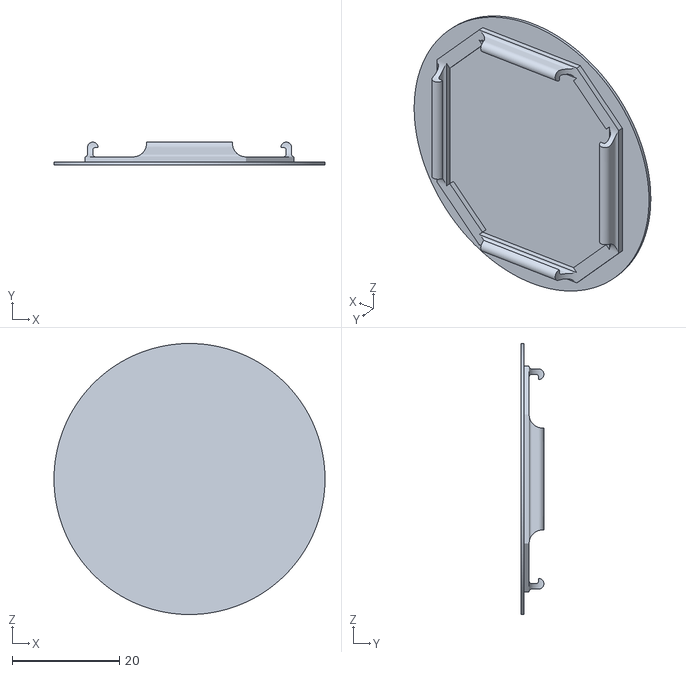
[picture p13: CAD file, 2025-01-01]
chassis/New Concept/Blinky Chassis B rev 6.stl
50.5 x 4.25 x 50.5

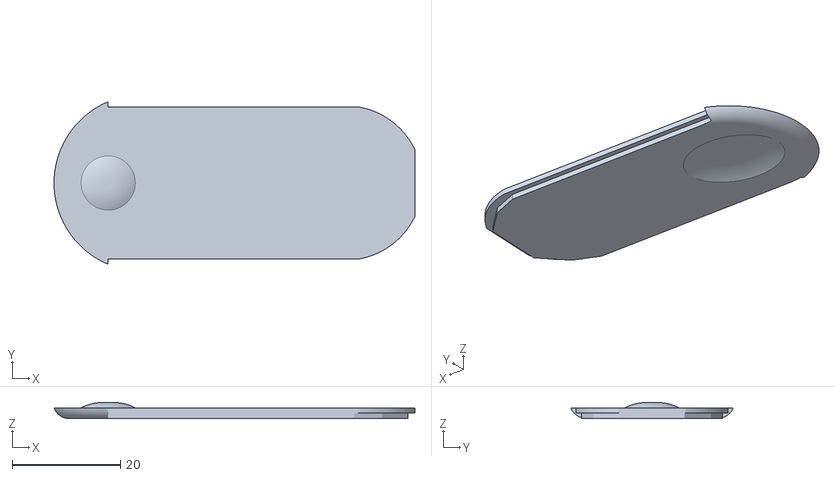
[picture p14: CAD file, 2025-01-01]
chassis/Remodel/test prints/cover.stl
66.6 x 30.0 x 3.00

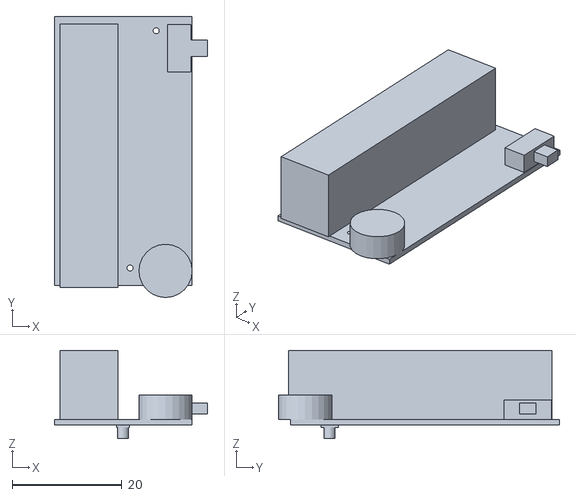
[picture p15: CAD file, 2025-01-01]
chassis/STLs/Rev 3.0/PCB rev 3.0.stl
27.9 x 51.2 x 16.1

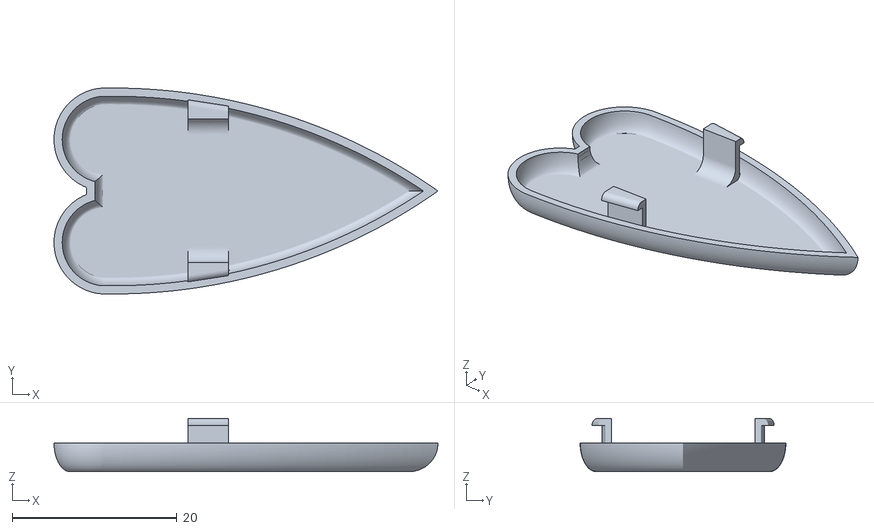
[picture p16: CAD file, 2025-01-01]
chassis/123d/Rev 5 complete/STL/Plate.stl
46.6 x 25.0 x 6.50

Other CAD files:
code/blinky Code Rev5/blinky Code Rev5/src/grace/objs/Timer0_A3_init.obj
chassis/123d/Rev 8 final/STLs/Cover Rev 8.stl
chassis/Remodel/STLs JUN17/Cover JUN17.stl
code/blinky Code Rev5/blinky Code Rev5/src/grace/objs/WDTplus_init.obj
chassis/123d/Rev 6/Chassis rev 6.stl
chassis/123d/Rev 6/Home printer version/fresh start 2.stl
chassis/123d/Rev 6/Home printer version/fresh start.stl
chassis/123d/Rev 6/STLs/Chassis rev 6.1.stl
chassis/123d/Rev 6/abs is shit.stl
chassis/123d/Rev 6/chassis improved supports.stl
chassis/123d/Rev 6/chassis rev 7.stl
chassis/123d/Rev 6/cover hand pruned.stl
chassis/123d/Rev 6/cover inter.stl
chassis/123d/Rev 6/cover rev 6.stl
chassis/123d/Rev 6/cover rev 7.stl
chassis/123d/Rev 6/cover test vertical.stl
chassis/123d/Rev 6/cover test.stl
chassis/123d/Rev 6/cover with optimize.stl
chassis/123d/Rev 6/hand pruned.stl
chassis/123d/Rev 6/injection mold test.stl
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

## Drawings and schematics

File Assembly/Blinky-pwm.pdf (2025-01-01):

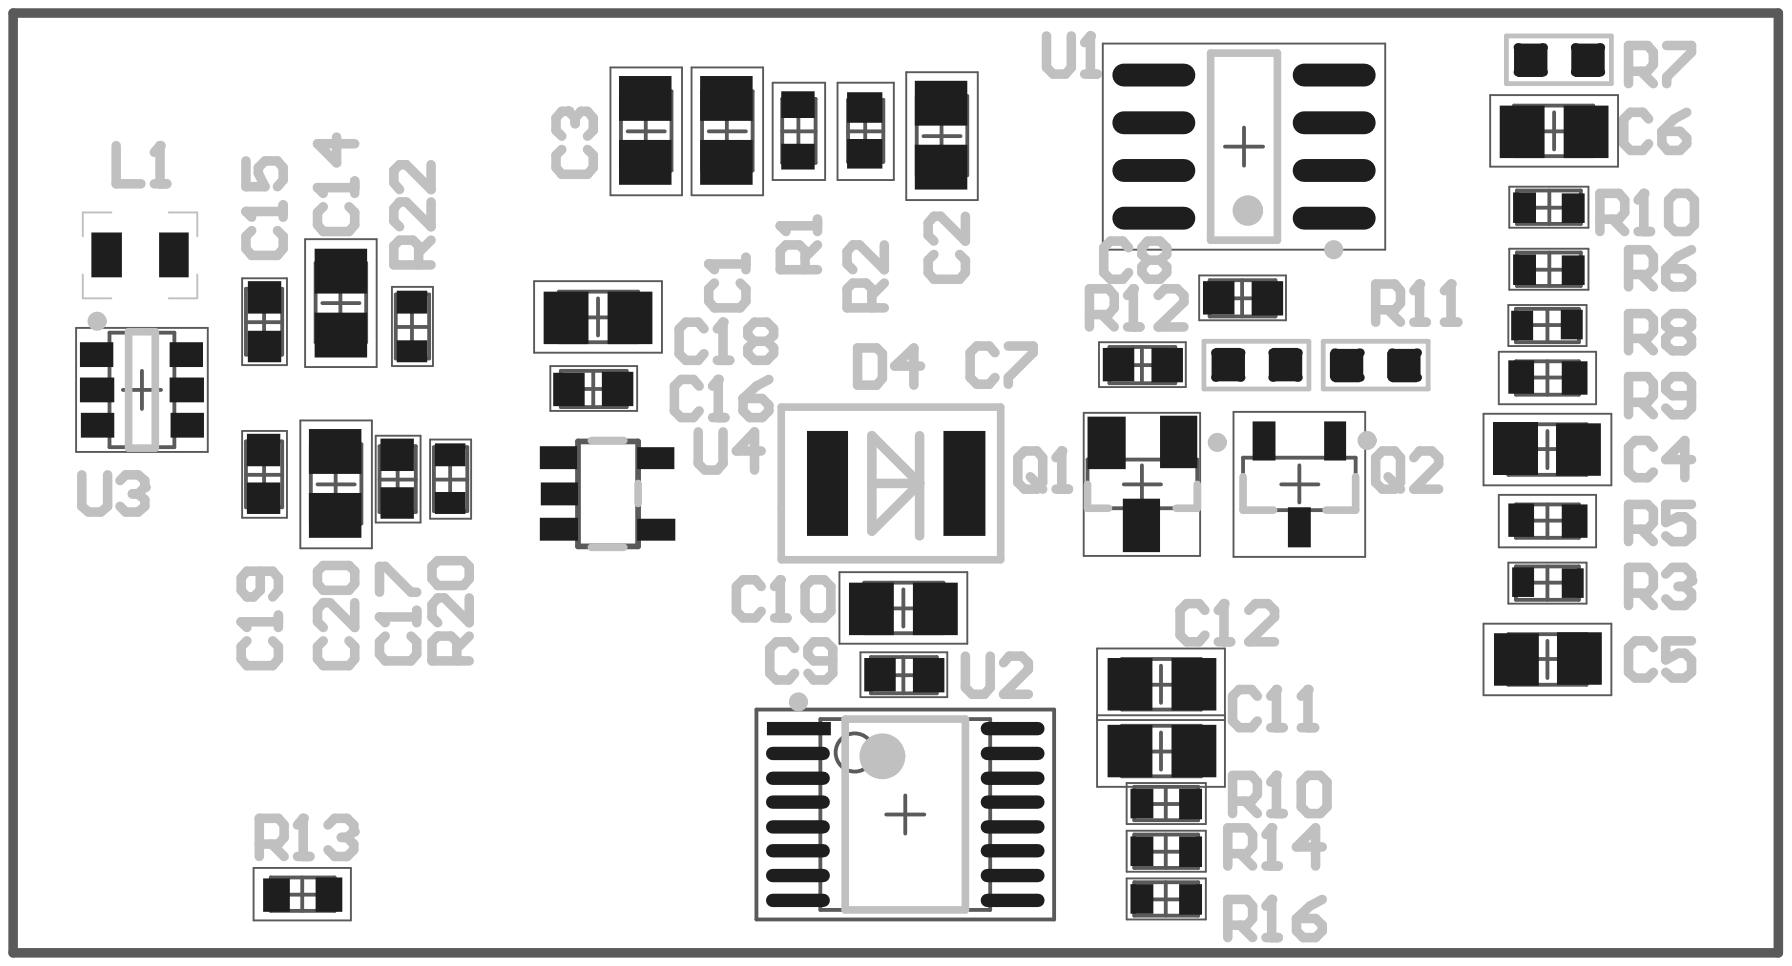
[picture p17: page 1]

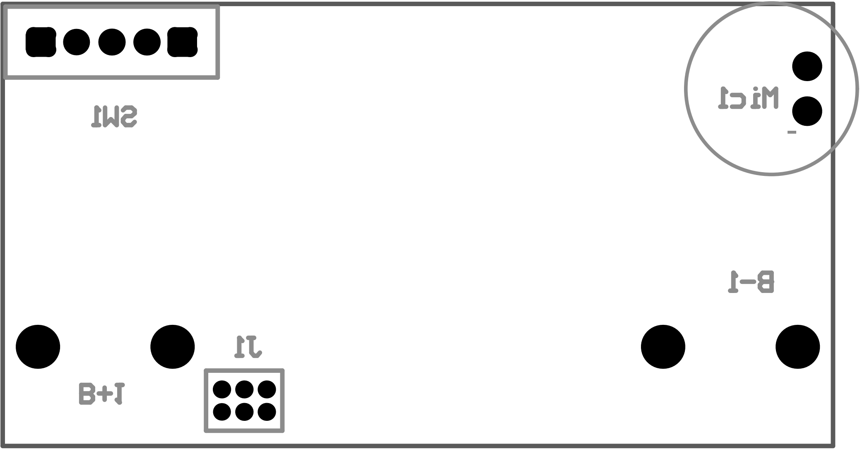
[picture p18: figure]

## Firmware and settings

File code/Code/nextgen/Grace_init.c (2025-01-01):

/*
 *  ======== Grace_init.c ========
 *  DO NOT MODIFY THIS FILE - CHANGES WILL BE OVERWRITTEN
 */

/* external peripheral initialization functions */
extern void GPIO_graceInit(void);
extern void BCSplus_graceInit(void);
extern void ADC10_graceInit(void);
extern void InterruptVectors_graceInit(void);
extern void Timer0_A3_graceInit(void);
extern void Timer1_A3_graceInit(void);
extern void System_graceInit(void);

#include <msp430.h>

/* verify that the MSP430 headers included support the code that's generated */
#if defined(__TI_COMPILER_VERSION__)
  /* pragma required to suppress TI warning that #warning is unrecognized */
  #pragma diag_suppress 11
#endif
#if __MSP430_HEADER_VERSION__ < 1093
  #if defined(__TI_COMPILER_VERSION__)
    #warn The MSP430 headers included may be incompatible with the generated source files.  If the value of __MSP430_HEADER_VERSION__, declared by msp430.h, is less than 1093, please update your version of the msp430 headers.
  #elif defined(__GNUC__) || defined(__IAR_SYSTEMS_ICC__)
    #warning The MSP430 headers included may be incompatible with the generated source files.  If the value of __MSP430_HEADER_VERSION__, declared by msp430.h, is less than 1093, please update your version of the msp430 headers.
  #else
    /* if we can't just warn, resort to ANSI C's #error */
    #error The MSP430 headers included may be incompatible with the generated source files.  If the value of __MSP430_HEADER_VERSION__, declared by msp430.h, is less than 1093, please update your version of the msp430 headers.
  #endif
#endif
#if defined(__TI_COMPILER_VERSION__)
  /* pragma required to restore TI warnings about unrecognized directives */
  #pragma diag_default 11
#endif

/*
 *  ======== Grace_init =========
 *  Initialize all configured Grace peripherals
 */
void Grace_init(void)
{
    /* Stop watchdog timer from timing out during initial start-up. */
    WDTCTL = WDTPW | WDTHOLD;

    /* initialize Config for the MSP430 GPIO */
    GPIO_graceInit();

    /* initialize Config for the MSP430 2xx family clock systems (BCS) */
    BCSplus_graceInit();

    /* initialize Config for the MSP430 10-bit Analog to Digital Converter (ADC) */
    ADC10_graceInit();

    /* initialize Interrupt vector support */
    InterruptVectors_graceInit();

    /* initialize Config for the MSP430 A3 Timer0 */
    Timer0_A3_graceInit();

    /* initialize Config for the MSP430 A3 Timer0 */
    Timer1_A3_graceInit();

    /* initialize Config for the MSP430 System Registers */
    System_graceInit();
}
